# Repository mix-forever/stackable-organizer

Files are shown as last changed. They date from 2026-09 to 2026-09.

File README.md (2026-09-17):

# Parametric Stackable Organizer



Stackable drawer boxes for a workshop, generated to any size you need.
Resistors, screws, connectors, beads — whatever comes in small quantities and
has to stay sorted. Build a box, a drawer, an open bin or a connector clip on
the grid, and the parts stay **dimensionally compatible with the original
printed models**, so new pieces clip onto boxes you already have.

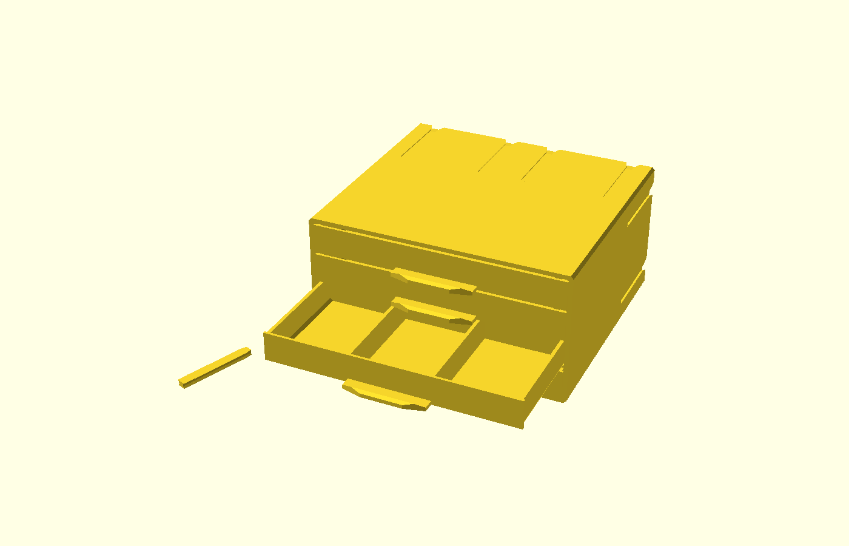
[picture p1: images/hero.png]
Box with drawers and a connector clip


---

## Credits and licence

This is a derivative work. The original design is not mine:

- **Various Size Stackable Resistor Storage Box** by **termlimit** —
  https://www.thingiverse.com/thing:3873672
- based on the original storage box by **STTrife**

The parametric rebuild in this repository was written by me together with
**Claude Code** — Anthropic's Claude in the terminal. The measurements, the
design decisions and the test prints are mine; the code was written in
dialogue with it, and every commit carries a `Co-Authored-By` line to say so.

Licence: **Creative Commons — Attribution — NonCommercial (CC BY-NC)**,
inherited from the original. Attribution to termlimit and STTrife is required,
and **commercial use is not permitted**.

> **Before uploading anywhere:** several model platforms run paid or
> points-based reward programmes. Publishing a CC BY-NC derivative into such a
> programme may conflict with the NonCommercial term. Check the platform's
> rules and the original licence before you monetise anything here.

---

## Gallery

| | |
|---|---|
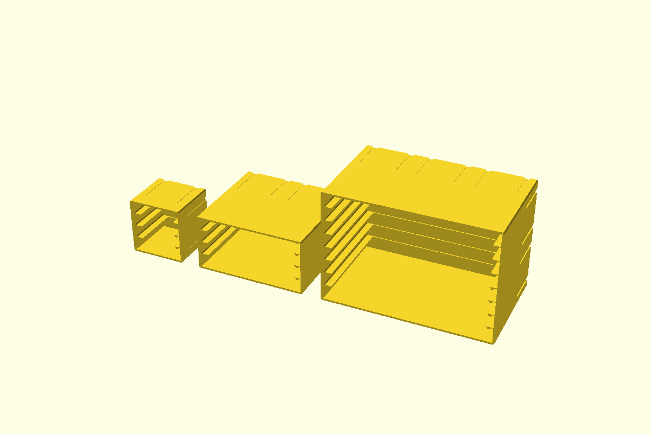
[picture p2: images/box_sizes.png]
Box sizes
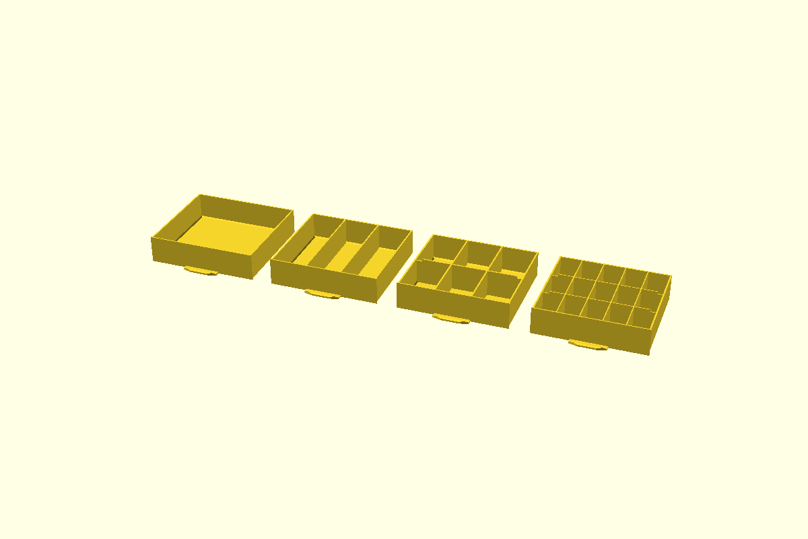
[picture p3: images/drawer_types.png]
Drawer layouts
|  **Boxes** — 1×1×1, 2×2×1 and 3×2×2 |  **Drawers** — 1, 3, 6 and 15 compartments |
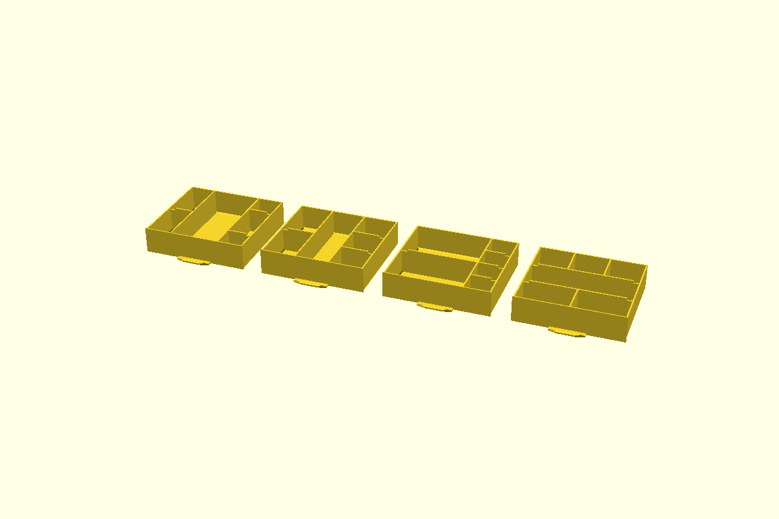
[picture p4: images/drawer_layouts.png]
Mixed compartments
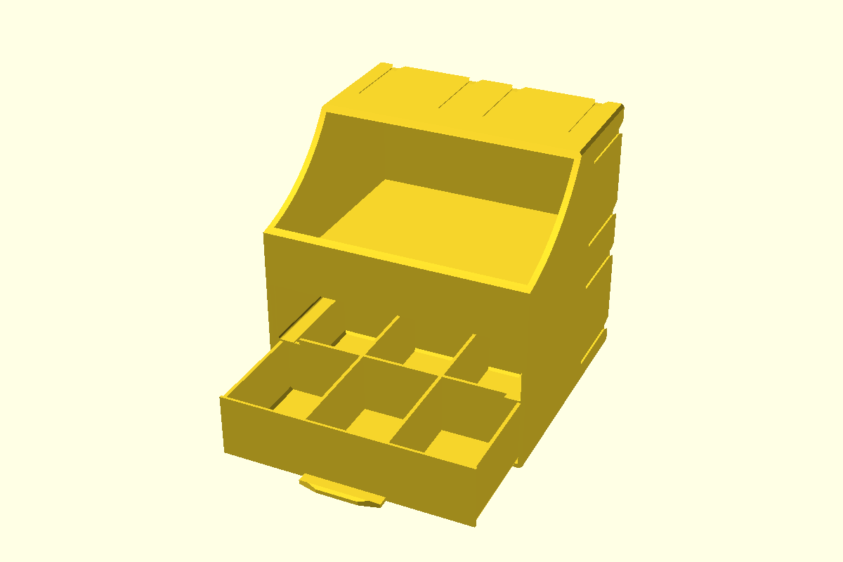
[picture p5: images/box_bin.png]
Box with a bin
|  **Mixed compartments** — a different split per column |  **Drawers plus an open bin** |
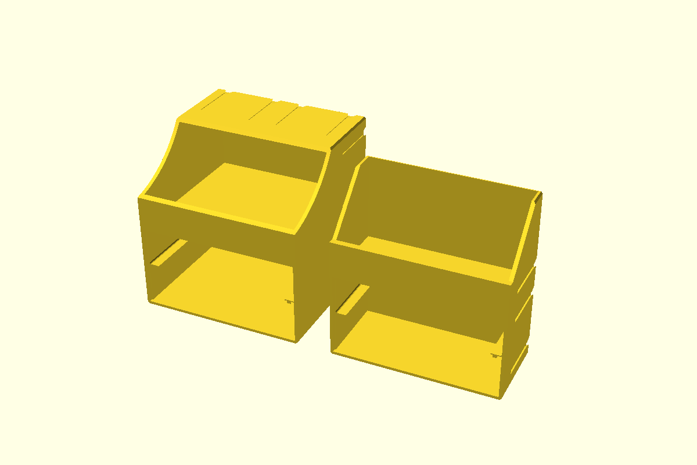
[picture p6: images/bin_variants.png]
Bin variants
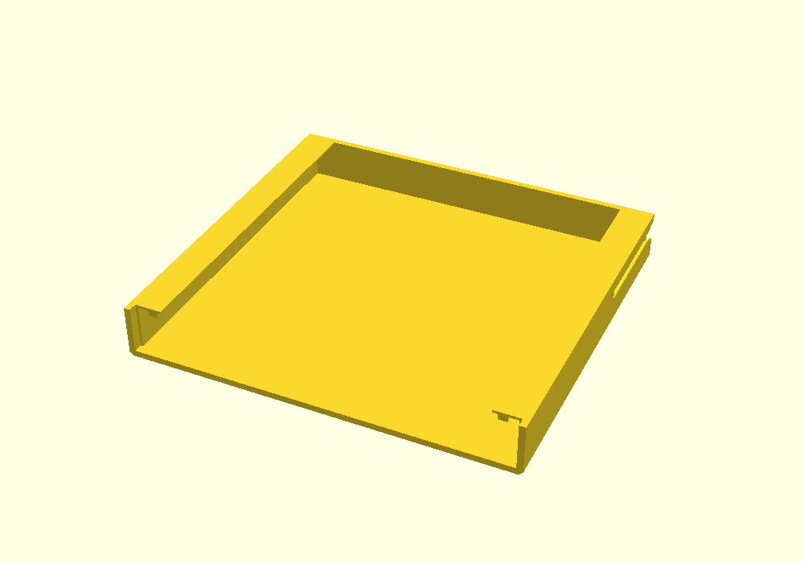
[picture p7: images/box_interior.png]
Drawer slot cutaway
|  **Deep bin with a roof vs. shallow open shelf** |  **Inside a slot** — rails and the anti-fallout catches |
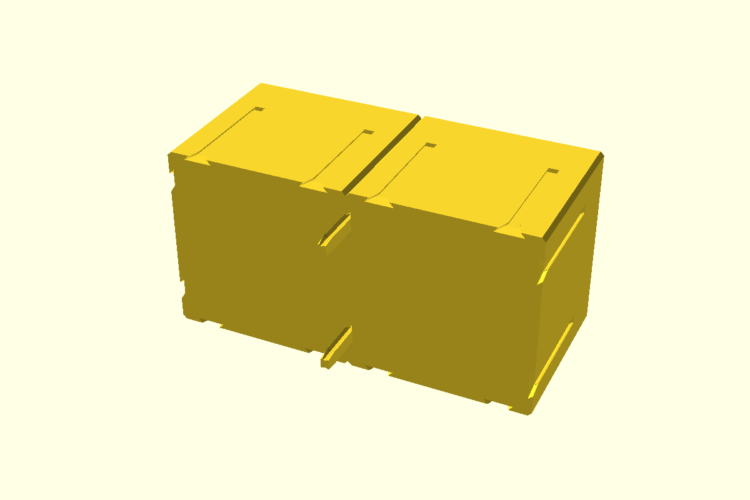
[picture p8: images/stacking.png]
Two boxes joined
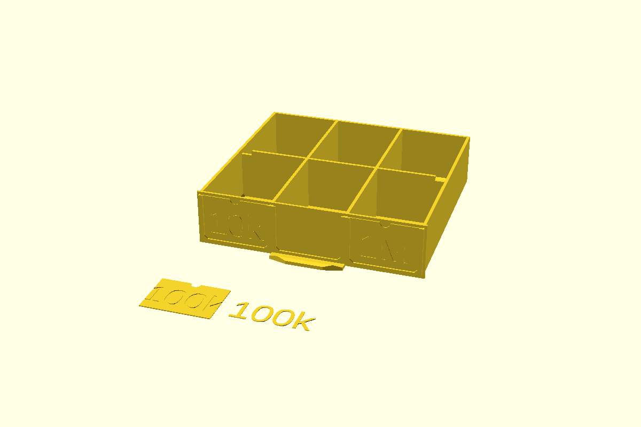
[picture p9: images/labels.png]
Label pocket
|  **Two boxes joined** with connector clips |  **Label pocket** — printed plates slide in |
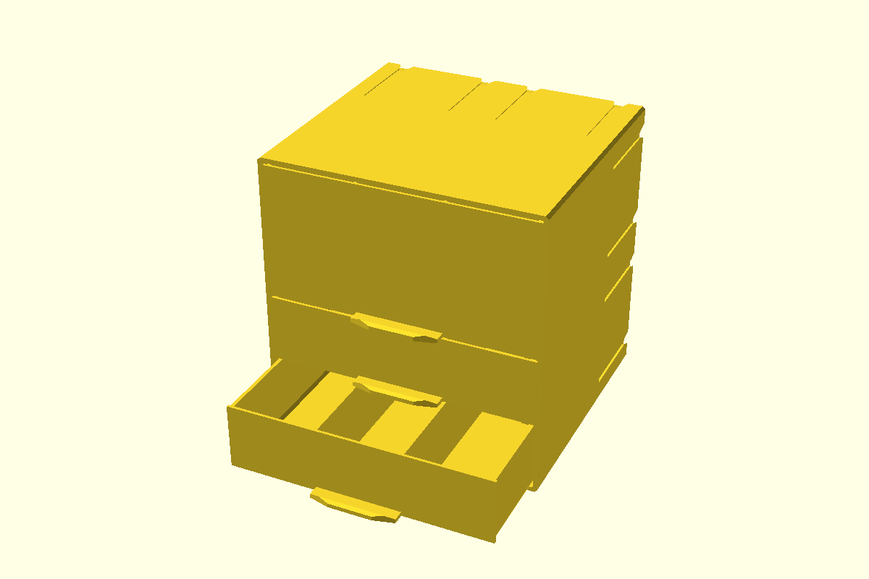
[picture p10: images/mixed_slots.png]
Slots of different heights
|  **Slots of different heights** in one box | |

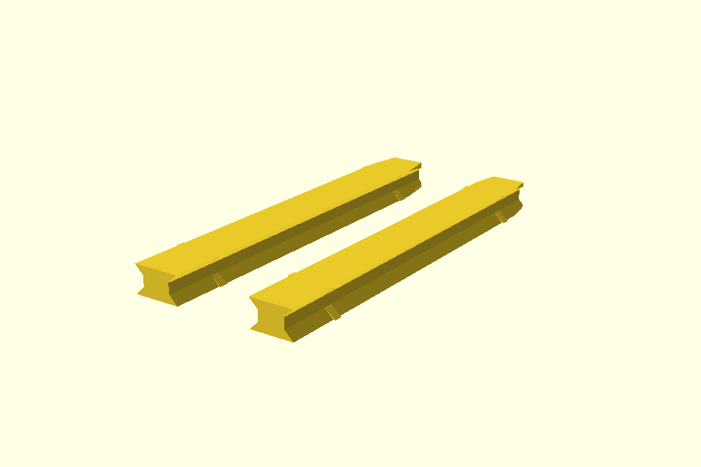
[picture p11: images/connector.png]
Connector clips


---

## Quick start

1. Install [OpenSCAD](https://openscad.org/) (2021.01 or newer).
2. Open **`presets.scad`** — this is the only file you need to touch.
3. `Window → Customizer`, pick a part and a size.
4. **F5** preview · **F6** render · **F7** export STL.

From the command line:

```sh
openscad -D 'part="drawer"' -D width_units=3 -D depth_units=2 \
         -D drawer_height_mm=34.66 -D compartments_across=5 \
         -D compartments_deep=3 -D divider_thickness=1.20 \
         -o my_drawer.stl presets.scad
```

Ready-made examples are in **`stl/`** — rebuild them any time with
`sh tools/build_examples.sh`.

---

## Parameters

Everything is set in `presets.scad`.

### What to generate

| Parameter | Meaning |
|---|---|
| `part` | `demo`, `box`, `box_bin`, `drawer`, `label`, `label_text`, `connector`, `connector_tolerant` |

### Size

| Parameter | Meaning |
|---|---|
| `width_units` | Width in grid units of **73.06 mm** (1, 2, 2.5, 3) |
| `depth_units` | Depth in grid units of **67.20 mm** (1, 2) |
| `height_units` | Height in grid units of **74.64 mm** (boxes only) |

### Drawer slots

| Parameter | Meaning |
|---|---|
| `drawer_slots` | How many drawer slots the box has **in total**. The drawer height follows automatically. |
| `drawer_height_mm` | Override the drawer height. Leave `0` to derive it from the slot count. |
| `drawer_for_slot` | Which slot this drawer is for, from the bottom. Only matters when the slots differ — see below. |

For a box one unit tall:

| Slots | Slot clearance | Matching drawer |
|---|---|---|
| 4 | 16.50 mm | **16.20 mm** |
| 2 | 33.96 mm | 33.66 mm |
| 1 | 68.88 mm | 68.58 mm |

#### Slots of different heights

Two shallow slots for resistors and one deep one for potentiometers, in the
same box: set **`slot_weights`** in `presets.scad` — one weight per slot,
bottom to top.

```scad
slot_weights = [1, 1, 2];   // two ordinary slots, then one twice as tall
```

A box with slots of different heights

The weights are relative and always fill the box, exactly like the compartment
weights in a drawer, so you never work out the millimetres yourself. Leave the
list empty for slots that are all the same.

Because the slots now differ, a drawer has to know which one it is for: set
**`drawer_for_slot`** (counted from the bottom). The console prints the whole
table, so you can see what to print for each:

```
slots (bottom to top): [35.4, 35.4, 70.8] mm — drawers: [35.1, 35.1, 70.5] mm.
This drawer is for slot 3, so 70.5 mm tall.
```

It works for the drawer section of a box with a bin as well.

### Drawer

| Parameter | Meaning |
|---|---|
| `compartments_across` | Compartments across the width |
| `compartments_deep` | Compartments front to back |
| `divider_thickness` | Divider thickness. Originals use 1.92 on 2-unit models, 1.20 on 3-unit ones. |
| `handle` | Pull handle under the front |

#### Compartments that are not a plain grid

`compartments_across` × `compartments_deep` gives equal compartments. For
anything else, set **`drawer_layout`** in `presets.scad` (it sits below the
Customizer settings, because the Customizer cannot show a list of lists).

One entry per column, front to back, written as `[width weight, [row weights]]`:

```scad
drawer_layout = [ [1, [1,1]],       // 2 equal rows
                  [2, [1]],         // twice as wide, undivided
                  [1, [1,2,1]] ];   // 3 rows, the middle one twice as deep
```

Drawers with mixed compartments

*Three columns split differently, the `[2,1,3]` shorthand, a wide half beside a
narrow one, and — on the right — the same idea turned through 90°.*

The weights are relative and always fill the drawer, so `[1,2,1]` and
`[10,20,10]` describe the same drawer and you never work in millimetres. A
plain number is shorthand for a standard-width column with that many equal
rows:

```scad
drawer_layout = [2, 1, 3];                       // columns of 2, 1 and 3 rows
drawer_layout = [ [3, [1,1]], [1, [1,1,1,1]] ];  // wide half in 2, narrow in 4
```

Cross dividers belong to their column, so each one is only as wide as that
column. `drawer_layout` overrides `compartments_across` and
`compartments_deep`; leave it `[]` to use those instead.

The same list can be read the other way round, with **`drawer_layout_dir`**:

| Value | Meaning |
|---|---|
| `"cols"` | Columns, each with its own rows (the default) |
| `"rows"` | Bands across the drawer, each with its own columns. The first weight is then the depth of the band. |

```scad
drawer_layout     = [ [1,[1,1]], [1,[1]], [1,[1,1,1]] ];
drawer_layout_dir = "rows";   // 3 bands: 2 columns, then none, then 3
```

The fourth drawer in the picture above is that one. Whichever way you read it,
the dividers that cross the drawer are notched for the catches and those
running front to back are not — so the drawer still closes.

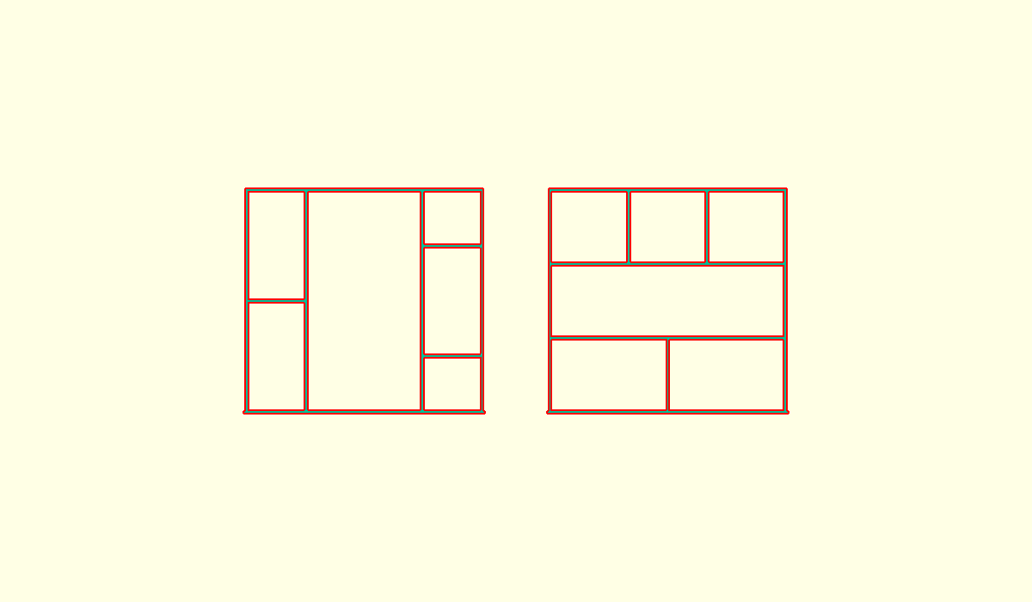
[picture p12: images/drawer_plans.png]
The same two layouts in plan


*The same two layouts seen from above, cut just above the floor: on the left
`[[1,[1,1]], [2,[1]], [1,[1,2,1]]]` read as columns, on the right
`[[1,[1,1]], [1,[1]], [1,[1,1,1]]]` read as bands. The drawer front — the
handle end — is at the bottom.*

#### Label pocket and printed plates

Set **`label_pocket`** and the drawer front grows the pocket the original
design has: two ribs and a shelf standing 1.76 mm proud of the face, with one
window per column of compartments. A card slides in from above — a strip of
paper, or a plate printed from this same library.

Label pocket with plates

The texts come from **`label_texts`** further down `presets.scad` (a list of
strings, which the Customizer cannot show):

```scad
label_texts = ["10k", "4k7", "220R"];
```

The plates come out laid in a row, flat, ready to print as generated. They are
built for **two-material printing**: the lettering is inlaid into the face, not
raised on top of it, so the text and the plate print side by side in the same
layers. That means two parts, cut from one and the same outline:

| `part` | What you get |
|---|---|
| `label` | the plates, with the letters cut out of the face |
| `label_text` | the lettering that fills those cut-outs |

Export both, then in your slicer (Bambu Studio, PrusaSlicer, OrcaSlicer) load
them **together as one object with multiple parts** — Bambu Studio offers this
as *“load as a single object with multiple parts?”*, and elsewhere you select
both and assemble them. They share one coordinate system, so the letters land
where they belong. Assign the plate one filament and the lettering another,
and print the row in one go.

There is deliberately **no clearance between the two parts** — the outlines
match exactly, and the slicer resolves the boundary. That is checked, not
assumed: `tools/check_fit.sh` fails if the two parts ever overlap or stop
adding up to a full plate.

| | |
|---|---|
| Slot in the pocket | 0.80 mm |
| Plate | 0.60 mm — 0.20 of backing plus 0.40 of inlaid lettering |
| Clearance to the pocket | 0.20 mm in thickness, 0.30 mm per side |
| Text size | fitted to the plate, or set `label_text_size` |

The backing means the first layer is all plate, and the two layers above it
carry both colours — so the counters of letters like **0** and **4** stay
attached instead of floating free. Each plate has a small notch in its top
edge, to pull it back out with a fingernail. `label_font` takes any font name
your OpenSCAD knows; leave it empty for the default.

Printing a single colour works too: the letters are then simply a 0.40 mm
recess in the face.

### Connector slots

| Parameter | Meaning |
|---|---|
| `slots_on_every_unit` | Slots on every grid unit, so any box clips anywhere. Off = only along the outer edges. |
| `slot_length_mm` | Slot length. Leave `0` for the standard 46.80 mm from the back face. |

### Open bin

| Parameter | Meaning |
|---|---|
| `bin_height` | Bin height in mm, from its floor to the top of the box. `0` = half the box. |
| `bin_drawer_slots` | Drawer slots below the bin. `0` = bin only. |
| `bin_lip_height` | Front lip that holds the contents in. Trimmed automatically if it would not fit. |
| `bin_front_flush` | Front panel flush with the face. Off = recessed behind the front frame. |
| `bin_roof` | Roof over the back of the bin. `auto` drops it when the box is too shallow for it to be useful. |

The bin adjusts itself when a setting does not fit — a shelf that would land on
the top face is moved down, an over-tall lip is trimmed, and slots that a clip
could no longer reach are dropped. Every adjustment is reported in the console,
so nothing changes silently.

---

## Printing

Test-printed: drawers in boxes of the original design, and a 2×2×2 box with
five slots plus its drawers. Still, check the fit on your first part before
printing a whole set.

| | |
|---|---|
| Orientation, boxes | Open front **facing up**. The drawer rails then print as vertical walls instead of overhangs. |
| Orientation, drawers | As generated, open side up. |
| Orientation, clips | Flat on the bed. |
| Supports | None needed in those orientations. The outer bottom and top edges are chamfered 1.5 mm for exactly this reason. |
| Layer height | 0.2 mm is a good default. The finest features (0.96 mm rail plates, 1.20 mm dividers) print fine at that. |
| Material | PLA or PETG. |

**Fit is tight by design.** Drawers have 0.35 mm clearance per side, and so do
the clips in their slots. If your printer runs wide, print
`connector_loose.stl` (0.15 mm narrower per side) instead of `connector.stl`.

The anti-fallout catches under each rail are **meant** to interfere: a drawer
is 15.80 mm tall in a 16.50 mm slot, and the catch hangs 2.30 mm into it. Tilt
the drawer to insert or remove it; in normal use it cannot be pulled out far
enough to fall.

In every slot above the lowest one the drawer rests on the small fillet where
the rail meets the side wall, about 0.2 mm higher than the slot floor. That is
expected and leaves about 0.1 mm above the drawer front. If drawers in the
upper slots feel tight, raise `DRAWER_CLEARANCE_H` in `params.scad`
(0.30 → 0.50): it makes the drawers lower without changing the boxes.

---

## Repository layout

| Path | What it is |
|---|---|
| `presets.scad` | **Open this.** All the settings live here. |
| `organizer.scad` | The modules: `box()`, `drawer()`, `connector()`, `box_drawer_bin()`, `label_plate()` |
| `params.scad` | Every dimension, in one place |
| `stl/` | Ready-to-print examples |
| `images/` | Gallery renders — rebuild with `tools/render_gallery.sh` |
| `tools/build_examples.sh` | Rebuilds `stl/` |
| `tools/render_gallery.sh` | Rebuilds `images/` |
| `tools/check_presets.sh` | Builds every part, fails on errors, warnings or empty output |
| `tools/check_fit.sh` | Checks the parts fit each other: a drawer in its slot, past the catches, a plate in its pocket |
| `.github/workflows/` | The same two checks on every push, plus example STLs attached to each release |
| `presets.json` | Customizer parameter sets |

Anything you export yourself (`.stl`, `.3mf`, `.pdf`) lands in the top folder
and is git-ignored, so your own prints never end up in a commit.

---

## Compatibility

Parts built here share the grid and the interlocking geometry of the system, so
they fit boxes you have already printed:

| | |
|---|---|
| Grid unit | 73.06 × 67.20 × 74.64 mm |
| Drawer clearance | 0.35 mm per side |
| Connector slot | 1.60 mm deep, 4.00 mm at the mouth, 6.00 mm at the bottom, 45° undercut |
| Slot length | 46.80 mm from the back face |
| Clip | 44.80 mm long, 3.20 mm thick — one clip fills the slots of two boxes |
| Divider notches | 7.00 mm in from each side wall, 3.00 mm deep |
| Label pocket | stands 1.76 mm proud of the front, 0.80 mm slot, card held 1.54 mm behind each rib |

That last one matters: the box has anti-fallout catches hanging below every
rail, and they reach inboard past the drawer's inner wall face. A divider
running full height across the drawer would hit them, so **cross dividers are
notched along both side walls** to let the catches pass. Without the notch a
drawer with cross dividers simply will not close.

Dividers running front to back keep their full height — they run parallel to
the catches. The one exception is a divider that lands in a catch's path,
which happens only with very many compartments across; it is notched as well,
and the console says so.

## Limitations

- **One-unit-wide drawers** are not built. That size needs an overlay front,
  wider than the box, which this library does not do.
- **Drawers one unit deep** need `drawer_height_mm` set explicitly.
- The box edges are chamfered 1.5 mm top and bottom for support-free printing.
  Set `EDGE_CHAMFER = 0` in `params.scad` if you want square edges.
- The **label pocket and the plates have not been test-printed yet** — the
  geometry is checked, the print is not. Try one drawer before a whole set.

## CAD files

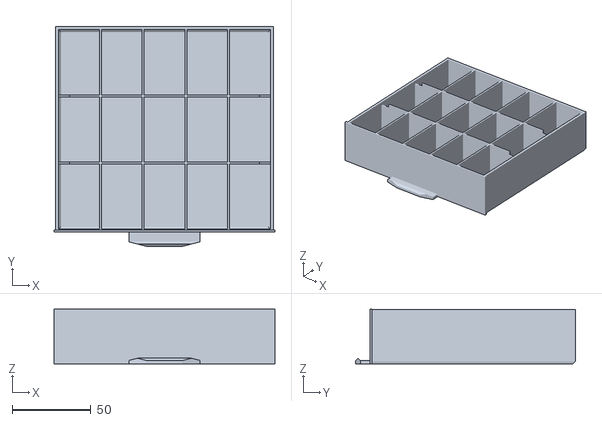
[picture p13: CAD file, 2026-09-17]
stl/drawer_2x2x2_15compartments.stl
140.6 x 139.8 x 34.9

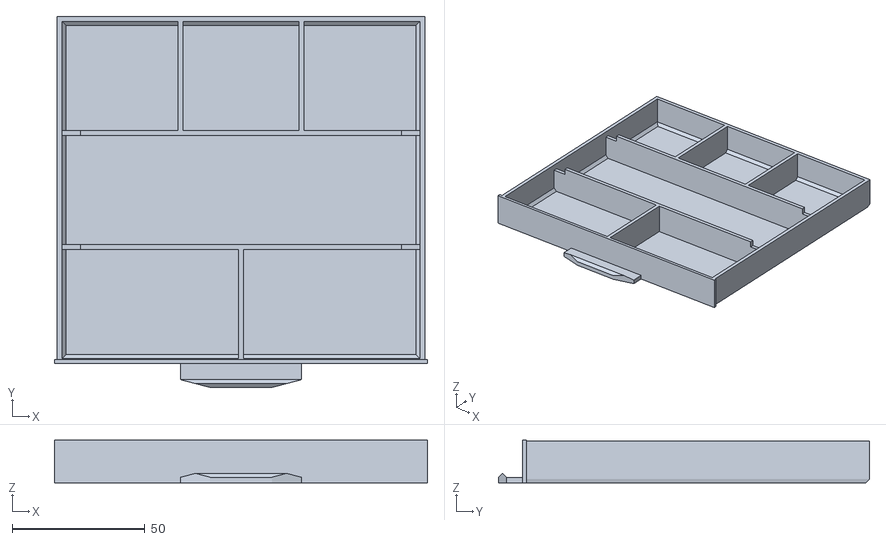
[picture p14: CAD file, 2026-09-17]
stl/drawer_2x2x1_mixed_bands.stl
140.6 x 139.8 x 16.2

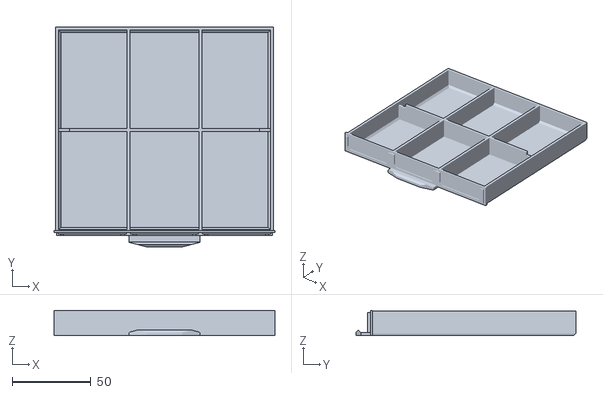
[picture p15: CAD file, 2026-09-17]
stl/drawer_2x2x1_label_pocket.stl
140.6 x 139.8 x 16.2

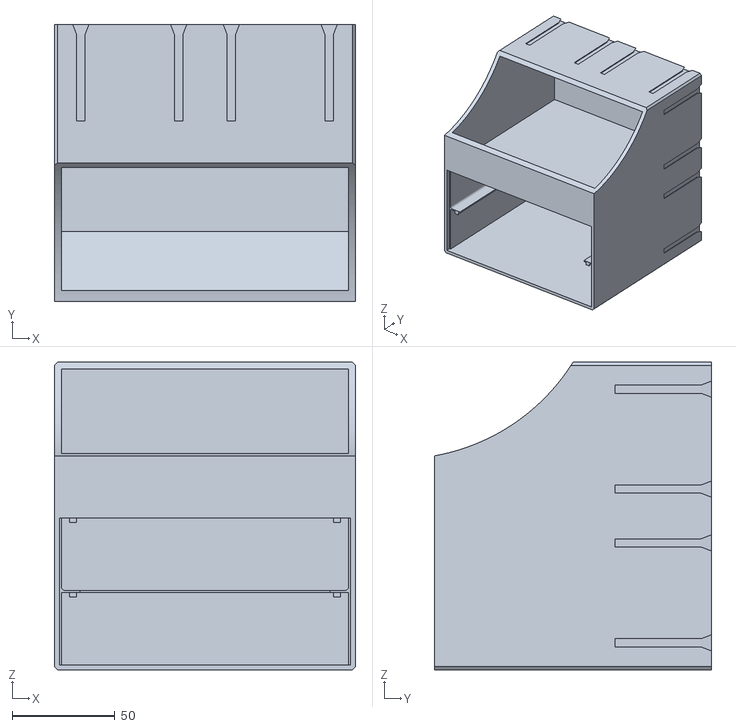
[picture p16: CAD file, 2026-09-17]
stl/box_2x2x2_drawers_and_bin.stl
146.1 x 134.4 x 149.3

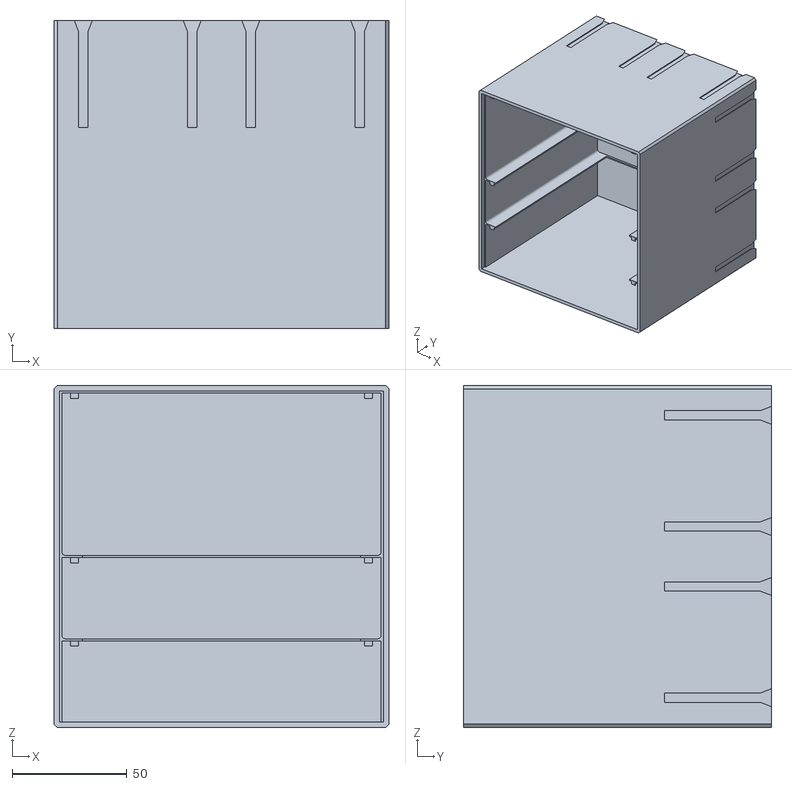
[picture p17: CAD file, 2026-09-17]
stl/box_2x2x2_mixed_slots.stl
146.1 x 134.4 x 149.3

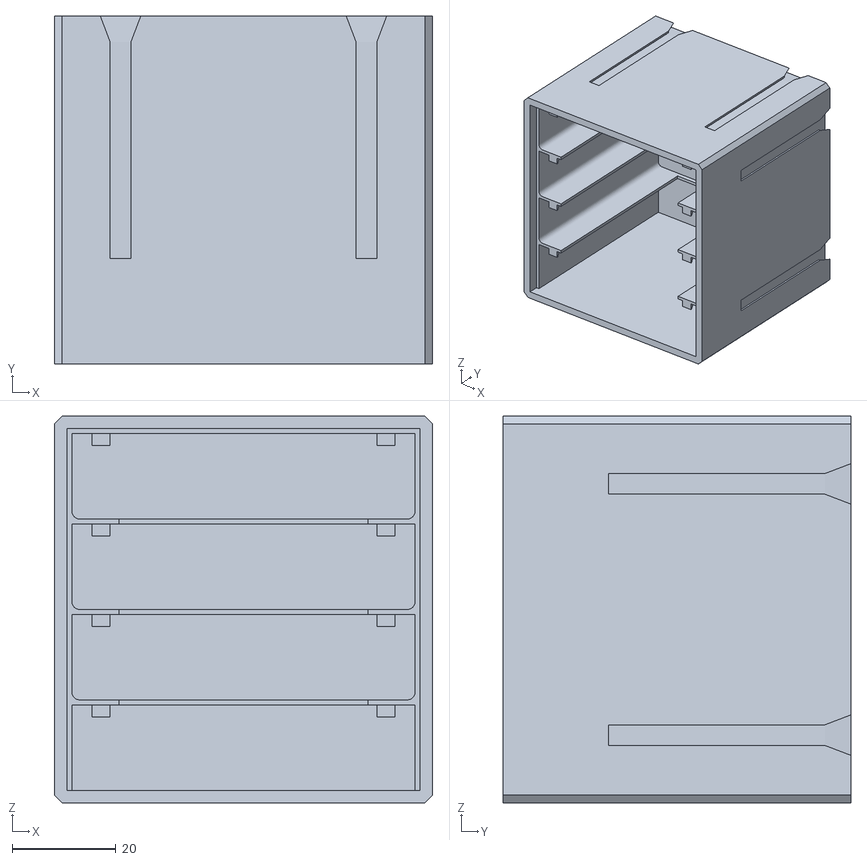
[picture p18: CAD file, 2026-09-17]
stl/box_1x1x1_4slots.stl
73.1 x 67.2 x 74.6

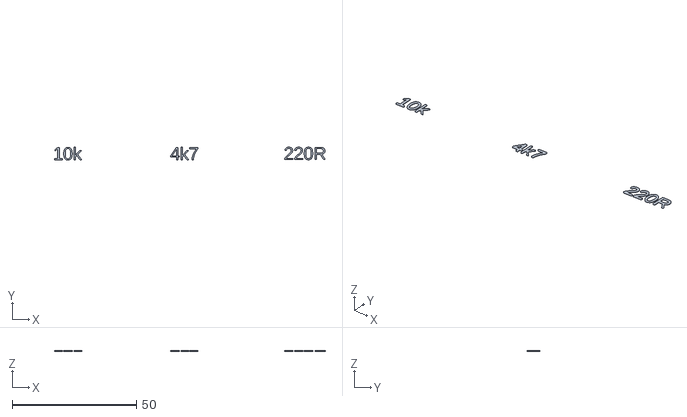
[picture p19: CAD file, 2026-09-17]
stl/label_plates_2x2x1_3x_text.stl
109.0 x 5.34 x 0.4

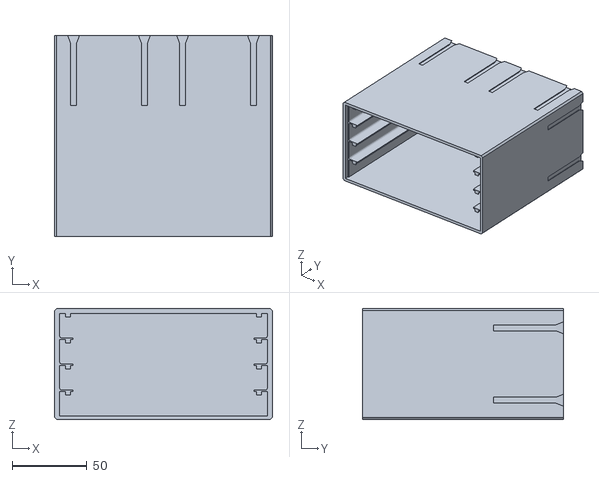
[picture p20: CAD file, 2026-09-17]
stl/box_2x2x1_4slots.stl
146.1 x 134.4 x 74.6

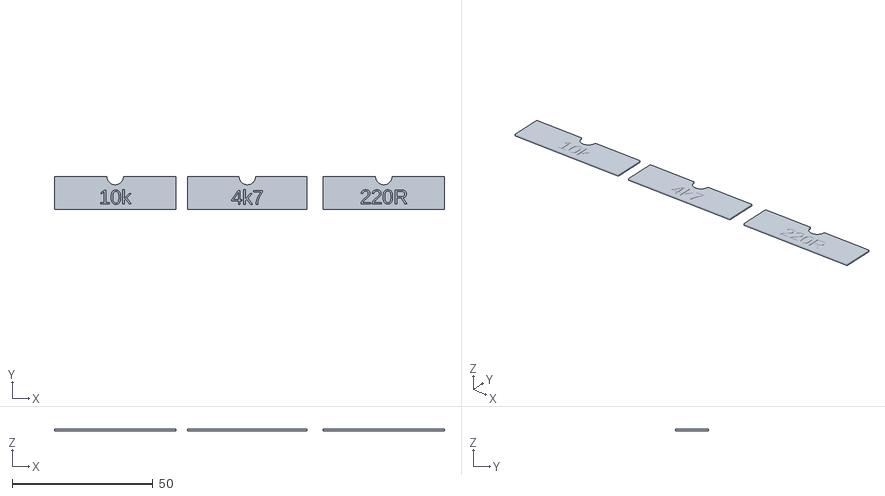
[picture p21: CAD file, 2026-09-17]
stl/label_plates_2x2x1_3x.stl
138.8 x 11.6 x 0.6

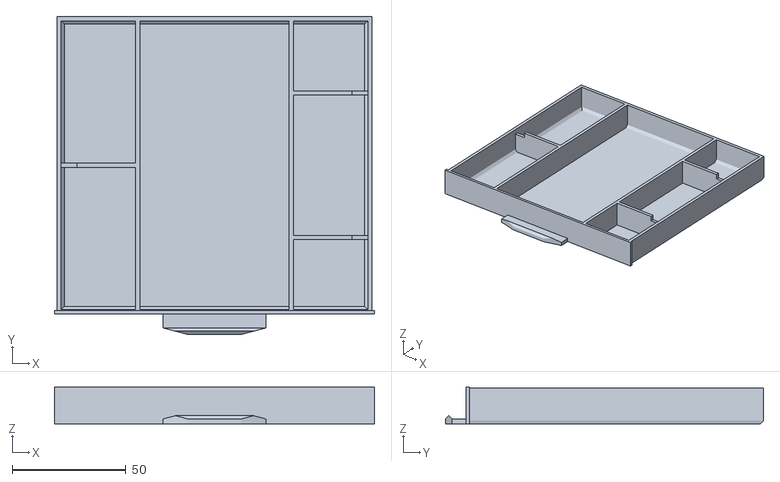
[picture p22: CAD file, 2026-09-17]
stl/drawer_2x2x1_mixed_layout.stl
140.6 x 139.8 x 16.2

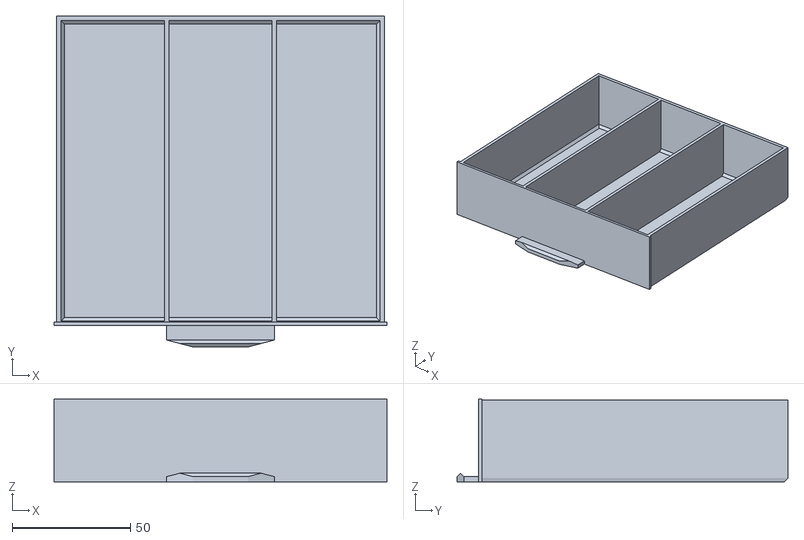
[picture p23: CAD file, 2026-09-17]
stl/drawer_2x2x2_3compartments.stl
140.6 x 139.8 x 34.9

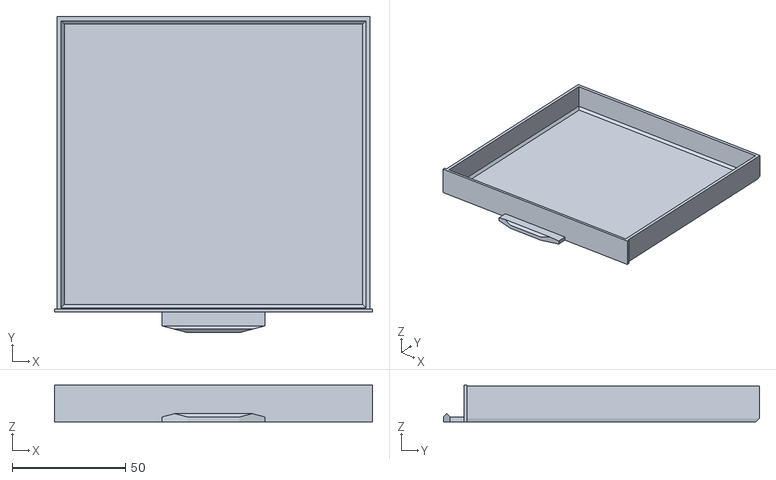
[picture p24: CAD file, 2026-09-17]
stl/drawer_2x2x1_plain.stl
140.6 x 139.8 x 16.2

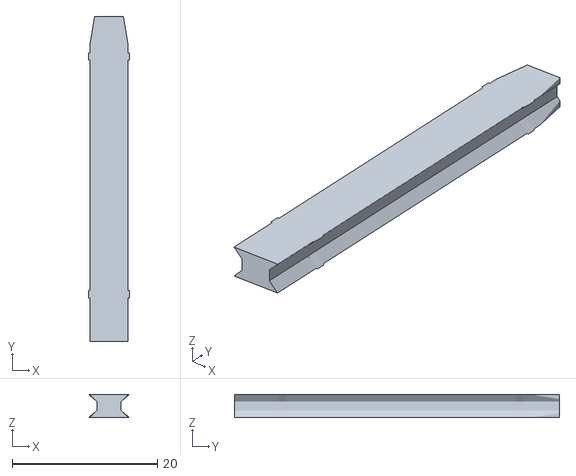
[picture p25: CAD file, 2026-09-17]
stl/connector.stl
5.65 x 44.8 x 3.20

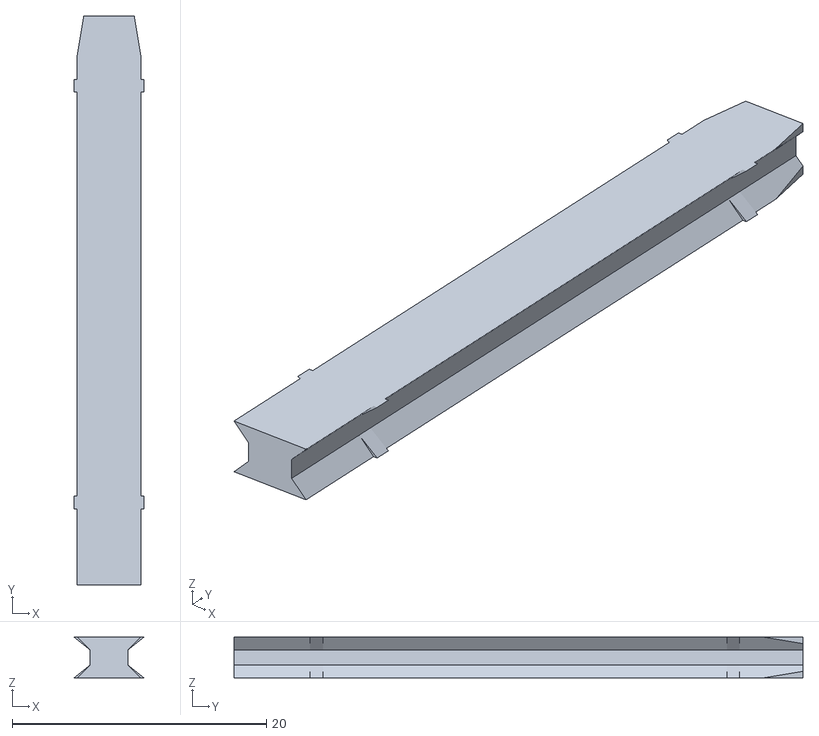
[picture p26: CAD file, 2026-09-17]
stl/connector_loose.stl
5.50 x 44.8 x 3.20

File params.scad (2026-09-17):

// params.scad — every dimension of the system in one place.
//
// Change a value here and every part follows. The grid unit is
// 73.06 × 67.20 × 74.64 mm (width × depth × height).
//
// Derivative work, CC BY-NC. Original design by termlimit, based on STTrife:
// https://www.thingiverse.com/thing:3873672

// ─── Base grid unit ──────────────────────────────────────────────────────────
// Outer size of a 1×1×1 box. All variants are whole multiples (plus 2.5×).
UNIT_L = 73.06;   // width  (X)
UNIT_D = 67.20;   // depth  (Y — front to back)
UNIT_H = 74.64;   // height (Z)

// ─── Box wall thicknesses ────────────────────────────────────────────────────
WALL_SIDE  = 3.40;   // left and right walls
WALL_BACK  = 1.00;   // back wall
WALL_FLOOR = 2.40;   // floor
WALL_TOP   = 3.36;   // ceiling
WALL_FRONT = 3.40;   // front flange (frame around the opening)
FRONT_RING = 2.40;   // width of that frame. The opening is this much smaller
                     // than the outer size on each side, and 1.00 per side
                     // WIDER than the cavity — that gap holds the drawer flange.

// Chamfers on the outer bottom and top edges, so it prints without supports.
EDGE_CHAMFER = 1.50;

// ─── Drawer slot grid ────────────────────────────────────────────────────────
// One height unit divides into 4 slots:
//   WALL_FLOOR + 4*POCKET_H + 3*RAIL_T + WALL_TOP == UNIT_H
POCKET_H = 16.50;   // clear height of one slot
RAIL_T   = 0.96;    // thickness of the rail plate the drawer rides on
RAIL_W   = 9.08;    // total rail reach from the wall (33.13 → 24.048)
RAIL_FLAT = 7.58;   // of which this much is the flat ledge (24.048 → 31.63)
RAIL_FILLET = 1.50; // R1.5 fillet where the rail meets the wall (19.86 → 21.36)
RAIL_PITCH = POCKET_H + RAIL_T;   // 17.46

// Rails run all the way into the back wall — no gap.
RAIL_BACK_GAP = 0.00;
// Back rib: at every rail level a ledge on the back wall joins the inner edges
// of the left and right rails, so each rail pair plus its rib forms a U-shaped
// frame that stiffens the box.
BACK_RIB_D = 1.50;   // how far the rib stands off the back wall (rib = RAIL_T thick)

// Anti-fallout catch at the front: a tab hanging below the rail that the
// drawer's rear wall runs into when pulled out. There is one under EVERY rail
// and one under the ceiling — one per drawer slot.
// The tab hangs 2.30 mm below the rail.
RAIL_STOP_DROP  = 2.30;   // how far it hangs below the rail
RAIL_STOP_GAP   = 0.20;   // tab face set back from the front flange
RAIL_STOP_FLAT  = 0.20;   // length at full depth
RAIL_STOP_RAMP  = 1.20;   // ramp length (slope 2.30/1.20)
// The tab does NOT span the whole rail width — it is inset from the wall so
// the drawer's SIDE wall passes beside it. The tab catches the drawer's REAR
// wall, not its side.
RAIL_STOP_INSET = 3.90;   // inset from the cavity wall face (33.13 → 29.23)
RAIL_STOP_W     = 3.46;   // width of the tab itself (29.23 → 25.78)
// Check: the drawer side wall's inner face sits 1.63 outboard of the tab,
// so the side of the drawer has clear passage.

// A drawer is this much shorter than its slot:
DRAWER_CLEARANCE_H = 0.30;   // a 16.50 slot takes a 16.20 drawer

// ─── Dovetail slots (the interlocking system) ────────────────────────────────
// The same profile on all four outer faces of a box.
DT_DEPTH      = 1.60;   // slot depth
DT_W_MOUTH    = 4.00;   // width at the surface
DT_W_FLOOR    = 6.00;   // width at the bottom (the undercut)
DT_STRAIGHT   = 0.60;   // straight run from the surface, then a 45° undercut
// The slot has a FIXED length and runs FROM THE BACK FACE forward — that is
// where the clip goes in before sliding forward. Length does not scale with
// box depth, because the clip does not either (44.80 long, so 46.80 leaves
// 2.00 of slack).
DT_LEN = 46.80;
// Pass `dovetail_len` to box() if you want a longer slot for some reason.
DT_INSET_FRONT = 20.40; // how far the slot stops short of the front face

// Enlarged ENTRY at the back face, where the clip is inserted.
// It tapers linearly to the standard section over DT_LEADIN_LEN.
DT_LEADIN_LEN     = 5.00;
DT_LEADIN_W_MOUTH = 7.80;   // mouth at the back face (standard 4.00)
DT_LEADIN_W_FLOOR = 11.25;  // floor at the back face (standard 6.00)
DT_LEADIN_DEPTH   = 1.93;   // depth at the back face (standard 1.60)

// Slot axis positions. On the side walls: measured from the box bottom and top.
DT_POS_FROM_H_EDGE = 13.062;
// On the top and bottom faces: measured from the box centre line.
DT_POS_FROM_AXIS   = 23.744;

// ─── Connector clip ──────────────────────────────────────────────────────────
// A bar with a dovetail cross-section; thickness = 2 × DT_DEPTH, so one clip
// fills the slots of two neighbouring boxes.
CONN_LEN       = 44.80;
CONN_T         = 2 * DT_DEPTH;   // 3.20
CONN_W_WAIST   = 3.30;           // waist (±1.65), for |z| <= CONN_WAIST_HALF
CONN_W_FACE    = 5.30;           // at the face (±2.65)
CONN_WAIST_HALF = 0.60;
CONN_TIP_TAPER = 5.00;           // tip taper (last 5 mm)
CONN_TIP_W     = 3.976;          // width of the tip face (±1.988)
// Clearance in the slot: (4.00-3.30)/2 = (6.00-5.30)/2 = 0.35 per side.

// Friction barbs: two bands where the face is widened. Waist unchanged.
CONN_BARB_W   = 5.65;            // face width at a barb (±2.825)
CONN_BARB_LEN = 1.00;
CONN_BARB_POS = [6.00, 38.80];   // start of each band, measured from the head
// At a barb the clearance drops from 0.35 to 0.175 per side — that is the grip.

// The TOLERANT variant is narrower by this much per side (waist and face by
// 0.15, barbs by only 0.075):
CONN_TOLERANT_EXTRA      = 0.15;
CONN_TOLERANT_EXTRA_BARB = 0.075;

// ─── Helpers ─────────────────────────────────────────────────────────────────
EPS = 0.01;   // to keep CSG cuts clean
$fn = 32;

// Outer size of a box given in grid units.
function box_size(ul, ud, uh) = [ul * UNIT_L, ud * UNIT_D, uh * UNIT_H];

// Drawer slot count of a box uh units tall, at 4 slots per unit.
function pocket_count(uh) = 4 * uh;

// ─── Link: slot count ↔ drawer height ────────────────────────────────────────
// The interior is divided into `pockets` slots separated by rails:
//   WALL_FLOOR + pockets*ph + (pockets-1)*RAIL_T + WALL_TOP == uh*UNIT_H
function pocket_height_of(uh, pockets) =
    (uh * UNIT_H - WALL_FLOOR - WALL_TOP - (pockets - 1) * RAIL_T) / pockets;

// Height of a drawer that fits such a slot.
function drawer_height_of(uh, pockets) =
    pocket_height_of(uh, pockets) - DRAWER_CLEARANCE_H;

// Reference values:
//   pocket_height_of(1, 4) = 16.50  → drawer 16.20
//   pocket_height_of(1, 2) = 33.96  → drawer 33.66
//   pocket_height_of(1, 1) = 68.88  → drawer 68.58
//   pocket_height_of(2, 4) = 35.16  → drawer 34.86

// ─── Drawer ──────────────────────────────────────────────────────────────────
// Inset front flange plus a bottom pull handle. These formulas cover drawers
// two grid units wide and up; a one-unit drawer needs an overlay front, which
// this library does not build.
DRAWER_CLEAR_SIDE = 0.35;   // clearance per side (same as the clip in its slot)
DRAWER_TOP_DROP   = 0.40;   // walls lower than the front flange
DRAWER_BACK_INSET = 3.618;  // body length = ud*UNIT_D − this value
DRAWER_WALL       = 1.92;   // side, front and back walls
DRAWER_FLOOR      = 0.80;   // floor
DRAWER_FLANGE_T   = 1.50;   // front flange thickness
DRAWER_DIV_T      = 1.92;   // divider thickness — 2-unit family
DRAWER_DIV_T_3U   = 1.20;   // divider thickness — slimmer, for many compartments
// Divider thickness is a parameter because it is a trade-off: thicker is
// stiffer, thinner leaves more usable space. drawer() also takes a separate
// thickness and a height drop for the cross dividers.

// Notches for the box's anti-fallout catches.
// The catches hang below every rail and reach inboard past the drawer's inner
// wall face, so any divider that runs full height across the drawer would
// collide with them and stop the drawer from closing. The dividers therefore
// get a channel cut out of their top edge along both side walls.
//
// Worst case over both box families, measured inboard from the drawer's inner
// wall face: the catch reaches 6.81 mm in, and drops 1.60 mm below the top of
// the drawer walls. These values clear that with margin:
DRAWER_NOTCH_W     = 7.00;   // how far inboard the notch reaches
DRAWER_NOTCH_DEPTH = 3.00;   // how far below the top of the walls it cuts.
                             // A catch reaches 1.60 below the wall top; the
                             // rest is clearance — 2.00 was found to catch on
                             // the rail stop in a test print.
// Where a catch actually travels, measured inboard from the inner face of the
// drawer's side wall. Only dividers reaching into this band have to be cut.
CATCH_BAND_0 = RAIL_STOP_INSET - DRAWER_CLEAR_SIDE - DRAWER_WALL;   // 1.63
CATCH_BAND_1 = CATCH_BAND_0 + RAIL_STOP_W;                          // 5.09
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

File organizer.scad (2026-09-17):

// organizer.scad — the parametric modules.
//
// Derivative work, CC BY-NC. Original design by termlimit, based on STTrife:
// https://www.thingiverse.com/thing:3873672
// Every dimension lives in params.scad.
//
// AXES: X = width, Y = depth (FRONT = Y 0, back = Y +D), Z = height (0..H).
// The box corner sits at (0,0,0), so parts drop straight onto the bed.

include <params.scad>

// ─── Dovetail slot profile ───────────────────────────────────────────────────
// A NEGATIVE solid. The worked surface lies at z=0 and the slot occupies
// z ∈ [−DT_DEPTH, 0] (i.e. it goes into −z), running along +Y for `len`.
// When placing it on a face, rotate so that local −Z points INTO the material.
// (Note: rotate([-90,0,0]) maps (x,y,z) → (x, z, −y), which is why the polygon
// y-coordinates are positive — after the rotation they become depth in −z.)
module dovetail_groove(len, leadin = DT_LEADIN_LEN) {
    rotate([-90, 0, 0]) {
        // the standard-section run
        translate([0, 0, leadin])
            linear_extrude(height = len - leadin) dt_profile();
        // entry: linear taper from the enlarged section to the standard one
        if (leadin > 0)
            hull() {
                linear_extrude(height = EPS) dt_profile(true);
                translate([0, 0, leadin - EPS])
                    linear_extrude(height = EPS) dt_profile();
            }
    }
}

// Slot cross-section. Surface at y=0, depth in +y (which the rotation turns
// into −z). The polygon is convex, so hull() produces a correct linear taper
// for the entry without flooding the undercut.
module dt_profile(wide = false) {
    mw = (wide ? DT_LEADIN_W_MOUTH : DT_W_MOUTH) / 2;
    fw = (wide ? DT_LEADIN_W_FLOOR : DT_W_FLOOR) / 2;
    dp =  wide ? DT_LEADIN_DEPTH   : DT_DEPTH;
    polygon([[ mw, -EPS], [ mw, DT_STRAIGHT], [ fw, dp],
             [-fw, dp], [-mw, DT_STRAIGHT], [-mw, -EPS]]);
}

// The full set of slots for a ul×ud×uh box, in box coordinates.
// Two slots per grid unit, so boxes of any size clip together anywhere on
// the grid.
// `side_z_max` — skip side-wall slots above this height. Used when the wall is
//   cut away at the top (bin) and too little of it is left for a clip to fit.
module box_dovetails(ul, ud, uh, per_unit = true, len_override = undef,
                     skip_top = false, side_z_max = undef) {
    W = ul * UNIT_L;  D = ud * UNIT_D;  H = uh * UNIT_H;
    // Fixed length from the back face (Y=D) forward — independent of box
    // depth, because the clip's length is fixed too. `len_override` is there
    // if you ever want a longer slot.
    len = is_undef(len_override) ? min(DT_LEN, D - WALL_FRONT) : len_override;

    // Slot heights on the side walls.
    zs_all = per_unit
        ? [ for (k = [0 : uh - 1], s = [0, 1])
              k * UNIT_H + (s == 0 ? DT_POS_FROM_H_EDGE
                                   : UNIT_H - DT_POS_FROM_H_EDGE) ]
        : [ DT_POS_FROM_H_EDGE, H - DT_POS_FROM_H_EDGE ];
    zs = is_undef(side_z_max)
        ? zs_all
        : [ for (z = zs_all) if (z <= side_z_max) z ];

    // Side walls: face X=0 (slot cuts into +x) and X=W (into −x).
    // mirror([0,1,0]) flips the extrusion direction so the slot runs from the
    // back face forward, putting the enlarged entry at the back.
    for (z = zs) {
        translate([0, D, z]) mirror([0,1,0]) rotate([0, -90, 0]) dovetail_groove(len);
        translate([W, D, z]) mirror([0,1,0]) rotate([0,  90, 0]) dovetail_groove(len);
    }

    // Slot positions on the top and bottom faces (from each unit's centre).
    xs = per_unit
        ? [ for (k = [0 : ul - 1], s = [-1, 1])
              (k + 0.5) * UNIT_L + s * DT_POS_FROM_AXIS ]
        : [ W/2 - DT_POS_FROM_AXIS, W/2 + DT_POS_FROM_AXIS ];

    for (x = xs) {
        translate([x, D, 0]) mirror([0,1,0]) rotate([0, 180, 0]) dovetail_groove(len);
        if (!skip_top)
            translate([x, D, H]) mirror([0,1,0])                 dovetail_groove(len);
    }
}

// ─── Box body ────────────────────────────────────────────────────────────────
// `pockets` — the drawer slots of the box. A number means that many equal
//   slots (the default is 4·uh, four per grid unit); a list of weights means
//   slots of different heights, e.g. [1,1,2] for a tall one on top.
//   Matching drawer heights: drawer_heights_of(uh, pockets).
module box(ul = 1, ud = 1, uh = 1, pockets = undef, rails = true,
           per_unit_dovetails = true) {
    hs = box_slot_heights(uh, is_undef(pockets) ? 4 * uh : pockets);
    np = len(hs);
    assert(min(hs) > 0, "box: a slot came out with no height — check the weights");
    assert(abs(slot_bottom(hs, np - 1) + hs[np - 1] + WALL_TOP - uh * UNIT_H) < 1e-6,
           "box: the slots do not add up to the height of the box");
    W = ul * UNIT_L;  D = ud * UNIT_D;  H = uh * UNIT_H;
    // Interior cavity.
    cx0 = WALL_SIDE;  cx1 = W - WALL_SIDE;
    cz0 = WALL_FLOOR; cz1 = H - WALL_TOP;
    cy1 = D - WALL_BACK;             // inner face of the back wall
    cy0 = WALL_FRONT;                // inner face of the front flange

    difference() {
        union() {
            // Block with chamfers on the bottom and top side edges.
            hull() {
                translate([EDGE_CHAMFER, 0, 0]) cube([W - 2*EDGE_CHAMFER, D, EPS]);
                translate([0, 0, EDGE_CHAMFER]) cube([W, D, H - 2*EDGE_CHAMFER]);
                translate([EDGE_CHAMFER, 0, H - EPS]) cube([W - 2*EDGE_CHAMFER, D, EPS]);
            }
        }

        // Cavity (from the front flange to the back).
        translate([cx0, cy0, cz0]) cube([cx1 - cx0, cy1 - cy0, cz1 - cz0]);

        // Front opening — wider than the cavity, leaving room for the drawer
        // flange.
        translate([FRONT_RING, -EPS, WALL_FLOOR])
            cube([W - 2*FRONT_RING, WALL_FRONT + 2*EPS, H - WALL_FLOOR - FRONT_RING]);

        // Connector slots.
        box_dovetails(ul, ud, uh, per_unit_dovetails);
    }

    // Drawer rails: np-1 pairs, on the slot boundaries.
    if (rails && np > 1)
        for (i = [0 : np - 2])
            rail_pair(W, cy1 - cy0 - RAIL_BACK_GAP,
                      slot_bottom(hs, i) + hs[i], cx0, cx1, cy0);

    // Anti-fallout catches: one per drawer slot — under every rail and under
    // the ceiling (for the topmost drawer).
    if (rails)
        for (i = [0 : np - 1]) {
            z = (i < np - 1) ? slot_bottom(hs, i) + hs[i] : H - WALL_TOP;
            for (m = [0, 1])
                translate([m ? cx1 : cx0, cy0, z])
                    mirror([m ? 1 : 0, 0, 0]) rail_stop();
        }
}

// A pair of rails (left + right) at height z (underside of the rail), plus the
// back rib joining their inner edges along the back wall. `len` runs from cy0
// to the inner face of the back wall.
module rail_pair(W, len, z, cx0, cx1, cy0) {
    for (m = [0, 1])
        translate([m ? cx1 : cx0, cy0, z])
        mirror([m ? 1 : 0, 0, 0])
        rail(len);
    translate([cx0 + RAIL_W - EPS, cy0 + len - BACK_RIB_D, z])
        cube([cx1 - cx0 - 2*RAIL_W + 2*EPS, BACK_RIB_D + EPS, RAIL_T]);
}

// The catch under the rail, at the front. Profile in the (Y, Z) plane: full
// depth for RAIL_STOP_FLAT behind the flange, then a ramp back up to the
// underside of the rail.
// In X it is only a narrow tab, inset by RAIL_STOP_INSET from the wall — the
// drawer's side wall passes beside it. The tab catches the drawer's rear wall.
module rail_stop() {
    // rotate([0,90,0]) maps (x,y,z) → (z, y, −x), so:
    //   the extrusion (local z) → +X (across the rail),
    //   the polygon's first coordinate → −Z, so the tab HANGS DOWN.
    translate([RAIL_STOP_INSET, 0, 0])
        rotate([0, 90, 0]) linear_extrude(height = RAIL_STOP_W)
            polygon([[0, RAIL_STOP_GAP],
                     [RAIL_STOP_DROP, RAIL_STOP_GAP],
                     [RAIL_STOP_DROP, RAIL_STOP_GAP + RAIL_STOP_FLAT],
                     [0, RAIL_STOP_GAP + RAIL_STOP_FLAT + RAIL_STOP_RAMP]]);
}

// One rail: a RAIL_FLAT ledge plus a fillet where it meets the wall.
// `z` at the call site is the rail's UNDERSIDE, so the plate must grow upward.
// rotate([-90,0,0]) maps the profile's second coordinate to −Z, so the 2D
// content is mirrored in Y first; without that the rail sits RAIL_T too low
// and every slot below it loses that much clearance.
module rail(len) {
    rotate([-90, 0, 0]) linear_extrude(height = len) mirror([0, 1]) {
        square([RAIL_W, RAIL_T]);
        // fillet against the wall, above the ledge
        difference() {
            square([RAIL_FILLET, RAIL_T + RAIL_FILLET]);
            translate([RAIL_FILLET, RAIL_T + RAIL_FILLET])
                circle(r = RAIL_FILLET, $fn = 24);
        }
    }
}
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

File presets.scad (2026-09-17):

// ═══════════════════════════════════════════════════════════════════════════
//  Parametric Stackable Organizer  —  OPEN THIS FILE
//
//  1. Open this file in OpenSCAD
//  2. Window → Customizer  (or edit the values below)
//  3. F5 preview · F6 render · F7 export STL
//
//  Derivative work, CC BY-NC. Original design by termlimit, based on STTrife:
//  https://www.thingiverse.com/thing:3873672
// ═══════════════════════════════════════════════════════════════════════════

include <organizer.scad>

/* [What to generate] */
// Part to build
part = "demo"; // [demo:Preview — box with drawers, box:Box with drawer slots, box_bin:Box with drawers and open bin, drawer:Drawer, label:Label plates — the plates, label_text:Label plates — the lettering, connector:Connector clip, connector_tolerant:Connector clip (loose fit)]

/* [Size] */
// Width, in grid units of 73.06 mm
width_units = 2;   // [1, 2, 2.5, 3]
// Depth, in grid units of 67.20 mm
depth_units = 2;   // [1, 2]
// Height, in grid units of 74.64 mm (boxes only)
height_units = 1;  // [1, 2, 3, 4]

/* [Drawer slots in the box] */
// How many drawer slots the box has in total. Drawer height follows
// automatically: 4 slots → 16.20 mm drawers, 2 → 33.66 mm, 1 → 68.58 mm
// (for a box one unit tall).
drawer_slots = 4;  // [1:1:8]
// Drawer height in mm. Leave 0 to derive it from the slot count (recommended).
drawer_height_mm = 0;
// Which slot the drawer is for, counted from the bottom. Only matters when the
// slots have different heights — see slot_weights further down the file.
drawer_for_slot = 1;  // [1:1:8]

/* [Drawer] */
// Number of compartments across the width
compartments_across = 3;  // [1:1:8]
// Number of compartments front to back
compartments_deep = 2;    // [1:1:6]
// Divider thickness in mm. 1.92 gives sturdy dividers; 1.20 is slimmer and
// leaves more usable space when you want many compartments.
divider_thickness = 1.92;
// Pull handle under the drawer front
handle = true;
// Label pocket on the drawer front: two ribs and a shelf, one window per
// column of compartments. A card or a printed plate slides in from above.
label_pocket = false;
// For compartments that are NOT all the same, leave the two settings above
// alone and edit `drawer_layout` further down this file — the Customizer
// cannot show a list of lists, so it lives in the text.


/* [Label plates] */
// Plates that slide into the pocket, printed flat for two-material printing.
// They come in two parts from the same outline: part = "label" is the plate
// with the letters cut out of its face, part = "label_text" is the lettering
// that fills them. Export both, load them into the slicer together as one
// object with two parts, and give each its own filament — the letters then
// print beside the plate in the same layers, not on top of it.
// The plates take their size from the drawer settings above. The texts are a
// list, so they live further down the file — the Customizer cannot show one.
// Text height in mm. 0 = size it to the plate.
label_text_size = 0;
// Font. Leave empty for the OpenSCAD default.
label_font = "";

/* [Connector slots] */
// Put slots on every grid unit, so any box can clip anywhere on the grid.
// Turn off for slots only along the outer edges.
slots_on_every_unit = true;
// Slot length in mm. Leave 0 for the standard 46.80 mm measured from the back.
slot_length_mm = 0;

/* [Open bin] */
// Bin height in mm, measured from the bin floor to the top of the box.
// 0 = half the box height, which gives a balanced split.
// Ignored when the bin has no drawers below it — then it fills the whole box.
bin_height = 0;
// Drawer slots below the bin. 0 = bin only, no drawers and no shelf.
bin_drawer_slots = 2;  // [0:1:6]
// Height of the front lip that keeps the contents in. Trimmed automatically
// if it would not fit the bin.
bin_lip_height = 28.56;
// Bin front panel flush with the face of the box.
// Turn off to recess it behind the front frame.
bin_front_flush = true;
// Roof over the back of the bin. Auto keeps it only when the box is deep
// enough to be useful — a one-unit-deep bin becomes an open shelf.
bin_roof = "auto"; // [auto, yes, no]

/* [Hidden] */
$fn = 64;

// ─── Compartments that are not a plain grid ─────────────────────────────────
// Leave empty to use compartments_across × compartments_deep above.
//
// Otherwise: one entry per column, front to back, written as
// [width weight, [row weights]]. The weights are relative and always fill the
// drawer, so [1,2,1] and [10,20,10] mean the same thing. A plain number is
// shorthand for a standard-width column with that many equal rows.
//
//   drawer_layout = [ [1, [1,1]],       // 2 equal rows
//                     [2, [1]],         // twice as wide, undivided
//                     [1, [1,2,1]] ];   // 3 rows, middle one twice as deep
//
//   drawer_layout = [2, 1, 3];          // 3 columns of 2, 1 and 3 rows
//
//   drawer_layout = [ [3, [1,1]], [1, [1,1,1,1]] ];
//                     // a wide half in 2 rows, a narrow half in 4
drawer_layout = [];

// Which way the layout is read:
//   "cols" — columns, each with its own rows   (the drawing above)
//   "rows" — bands across the drawer, each with its own columns; the first
//            weight is then the depth of the band
//
//   drawer_layout = [ [1,[1,1]], [1,[1]], [1,[1,1,1]] ];
//   drawer_layout_dir = "rows";   // 3 bands: 2 columns, none, 3 columns
drawer_layout_dir = "cols";
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

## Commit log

2026-09-17 Parametric stackable organizer
    An OpenSCAD library that generates stackable drawer boxes, open bins and
    connector clips on a 73.06 x 67.20 x 74.64 mm grid, dimensionally compatible
    with parts printed from the Various Size Stackable Resistor Storage Box.
    - box(), drawer(), connector() and box_drawer_bin() in organizer.scad;
    every dimension in params.scad; all settings in presets.scad
    - the drawer slot count is a parameter and the drawer height follows from it
    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
    [box_1x1x1_4slots.stl, box_2x2x1_4slots.stl, box_2x2x2_4slots.stl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]
2026-09-17 Label pocket on the drawer front, and plates to print for it
    The pocket is the one the original design has: two ribs and a shelf standing
    1.76 mm proud of the face, one window per column of compartments, a card
    sliding in from above. Two layers with different wall widths, so the card ends
    up wider than the window it shows through and the ribs hold it in.
    The plates are ours: printed flat, 0.60 mm thick, with the lettering raised by
    0.20 mm — one layer at 0.2 mm — so a filament change at the top layer prints
    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
    [box_1x1x1_4slots.stl, box_2x2x1_4slots.stl, box_2x2x2_4slots.stl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]
2026-09-17 Slots of different heights in one box
    `pockets` now takes either a count, as before, or a list of weights: [1,1,2]
    is two ordinary slots and one twice as tall. Same relative weights as the
    compartments in a drawer, so there is no new idea to learn, and they always
    fill the box exactly — asserted, not assumed.
    A drawer has to know which slot it belongs to now, so `drawer_for_slot` picks
    one and the console prints the whole table of slot and drawer heights. The
    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
    [box_1x1x1_4slots.stl, box_2x2x1_4slots.stl, box_2x2x2_drawers_and_bin.stl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]
2026-09-17 Run the checks on every push, and publish examples on a tag
    The fit test moves into the repository, translated: it checks the library
    against itself — a drawer in its slot, past the catches, a label plate in its
    pocket — with three deliberately wrong plates that must collide, so the case
    cannot pass by accident.
    checks.yml builds every part, runs both checks, and rebuilds stl/ to confirm
    the committed examples are what the current code produces (by volume, since
    the triangulation of one solid can differ between runs). release.yml packs the
    examples from the tagged source and attaches them to the release.
2026-09-17 Keep your own exports out of stl/
    OpenSCAD remembers the last export directory, so drawers exported by hand land
    in stl/ next to the generated examples. Ignore everything there except the
    example names; CI still fails if a real example goes missing.
2026-09-17 Label plates: inlaid lettering in two parts, for multi-material printing
    Raised text plus a filament change was the wrong shape for this. An AMS or MMU
    prints several colours in the same plane, so the lettering is now inlaid into
    the face of the plate and comes as a second part: `part = "label"` is the plate
    with the letters cut out, `part = "label_text"` is the letters. Both are built
    from one 2D outline, so they meet exactly — no clearance, the slicer resolves
    the boundary — and they are loaded into the slicer together as one object with
    two parts.
    The plate keeps a 0.20 mm backing under the 0.40 mm of lettering, so the
    counters of letters like 0 and 4 stay attached to something.
    Two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
    [box_1x1x1_4slots.stl, box_2x2x1_4slots.stl, box_2x2x2_4slots.stl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]
2026-09-17 Bring the README in line with what the library now does
    The part list was missing the two label modes, the module list the label
    plate, and the limitations did not say that the pocket and the plates have
    been checked but not yet printed.
